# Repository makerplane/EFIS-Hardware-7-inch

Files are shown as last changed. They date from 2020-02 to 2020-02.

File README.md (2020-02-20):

# EFIS-Hardware-7-inch
Hardware design files for 7" EFIS display

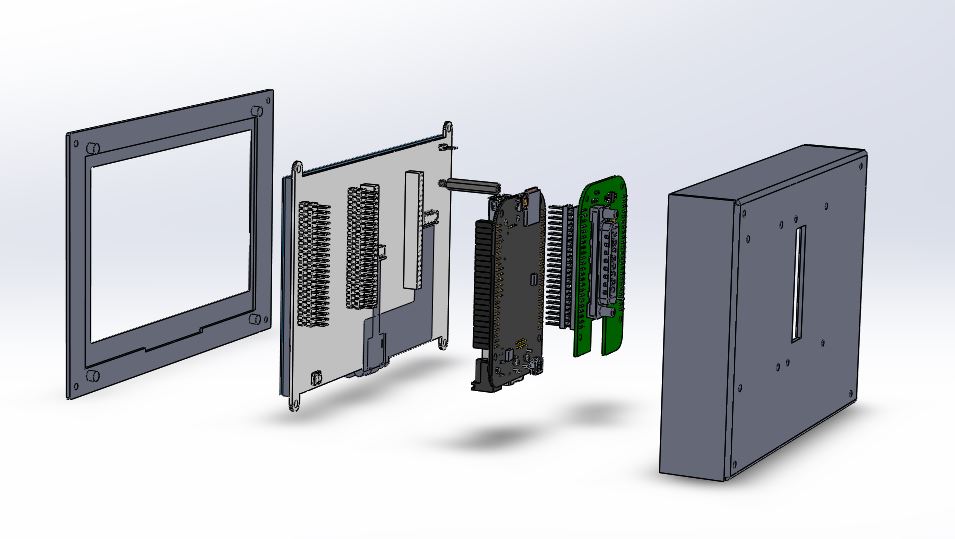
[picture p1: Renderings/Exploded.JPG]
Exploded View


Other required hardware:

[Beaglebone Black Rev C](https://www.digikey.com/product-detail/en/ghi-electronics-llc/BBB01-SC-505/BBB01-SC-505-ND/6210999)

[Newhaven 7" Display Cape](https://www.digikey.com/product-detail/en/newhaven-display-intl/NHD-7.0CTP-CAPE-N/NHD-7.0CTP-CAPE-N-ND/6622772)

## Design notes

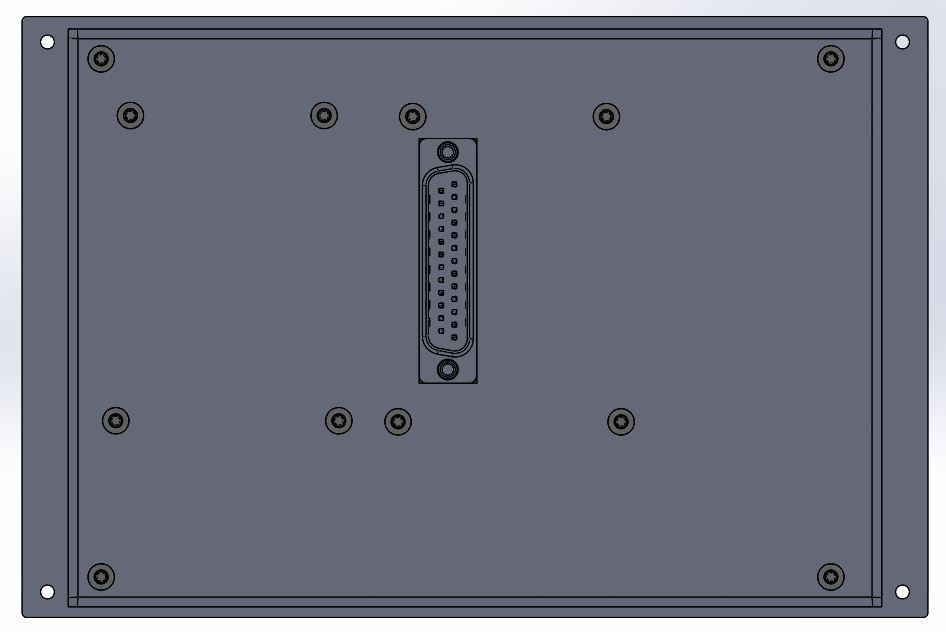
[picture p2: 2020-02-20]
Renderings/Back.JPG

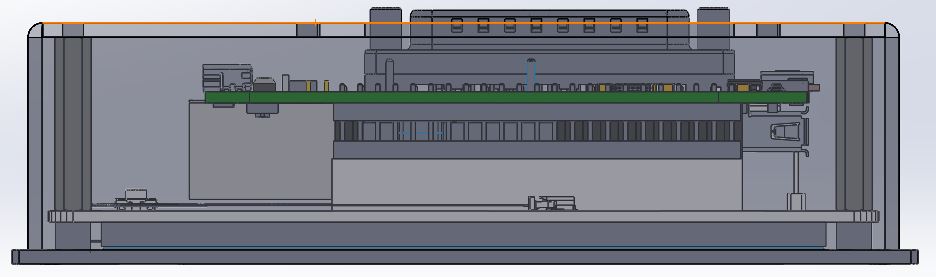
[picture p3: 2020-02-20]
Renderings/Cross Section Side.JPG

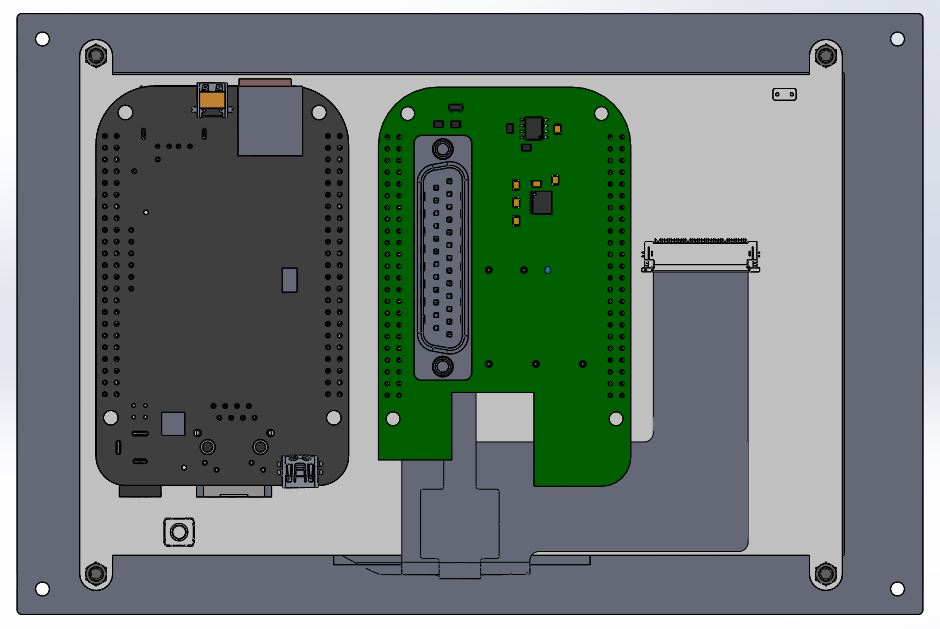
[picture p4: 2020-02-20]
Renderings/Back Removed.JPG

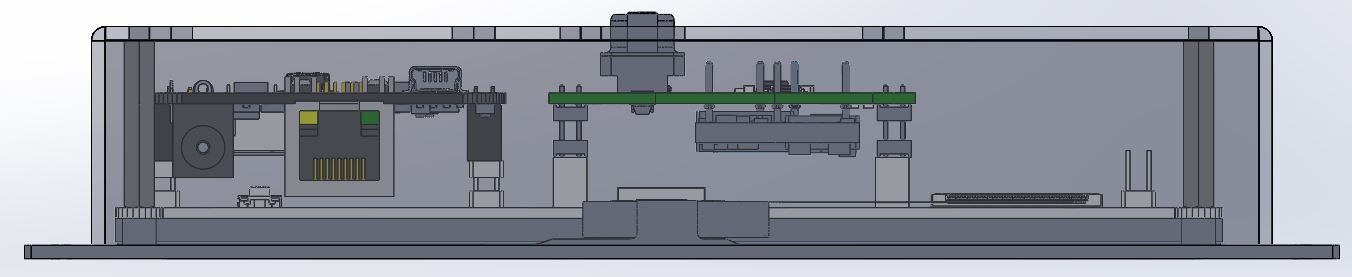
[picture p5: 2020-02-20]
Renderings/Cross Section Bottom.JPG

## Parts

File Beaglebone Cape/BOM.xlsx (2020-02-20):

Digikey Part | Part Number | Description | Designator | Quantity
 | DW-23-09-T-D-315 | CONN HDR 46POS 0.1 STACK T/H TIN |  | 2
609-1503-ND | D25P24A4GV00LF | DSUB25 Male |  | 1
MAX3232ECUE+TCT-ND | MAX3232ECUE+ | RS-232 Driver |  | 1
IRLML0030TRPBFCT-ND | IRLML0030TRPbF | Transistor | Q1 | 1
811-3682-ND | UEI15-050-Q12N-C | DC DC Converter 5V 15W |  | 1
296-11654-1-ND | SN65HVD230DR | IC TXRX CAN 1MBPS 3.3V 8SOIC |  | 1
A129738CT-ND | CRGCQ0805F120R | CRGCQ 0805 120R 1% |  | 1
1772-1896-ND‎ | ‎M2120-3005-AL‎ | HEX STANDOFF M3X0.5 ALUM 25MM |  | 4
‎1772-1109-ND‎ | ‎M1253-3005-AL‎ | HEX STANDOFF M3X0.5 ALUMINUM 6MM |  | 8

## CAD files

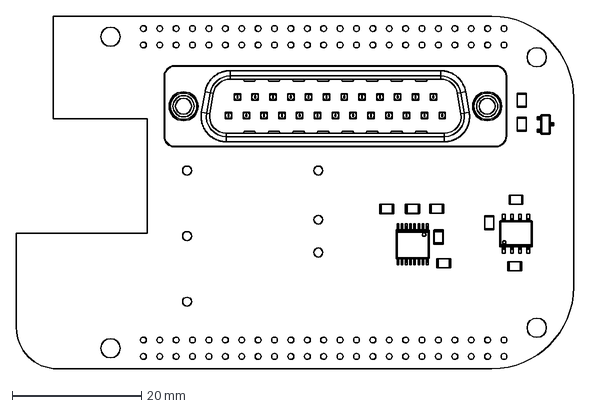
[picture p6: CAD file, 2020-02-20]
Beaglebone Cape/BeagleBoneCape Front.DXF
86.4 x 54.6 mm

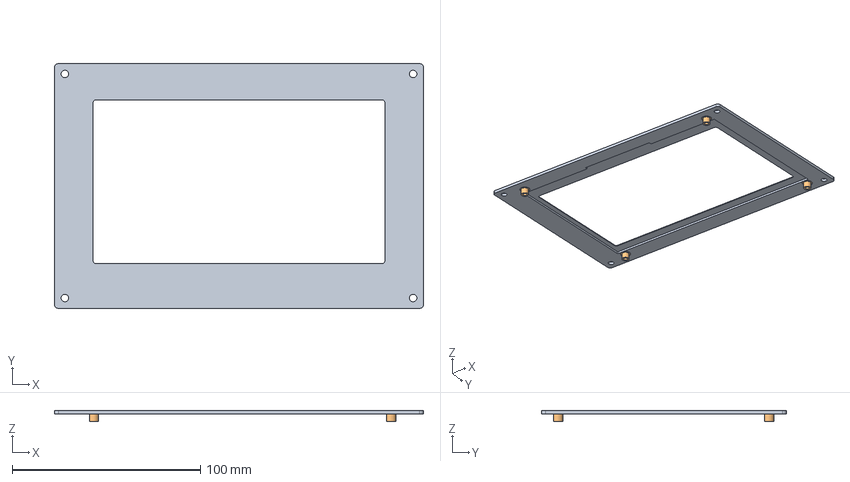
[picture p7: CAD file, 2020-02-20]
Enclosure/Front Panel.stp
196.0 x 130.0 x 6.00 mm

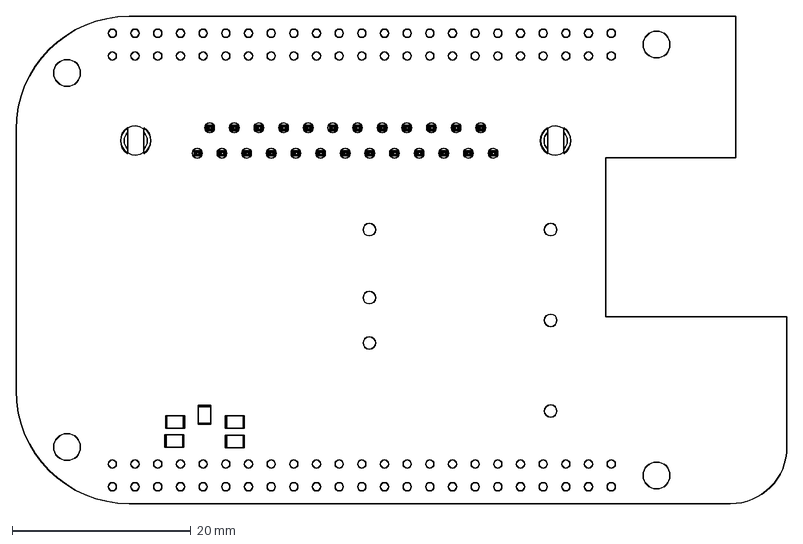
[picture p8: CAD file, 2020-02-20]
Beaglebone Cape/BeagleBoneCape Back.DXF
86.4 x 54.6 mm

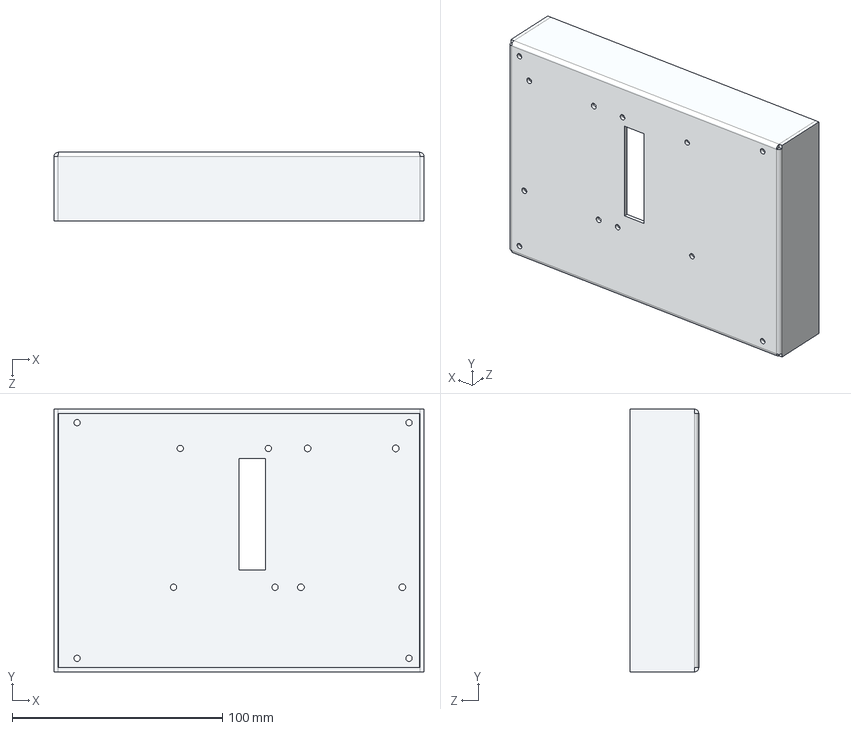
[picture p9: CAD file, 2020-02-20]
Enclosure/Back Case.STEP
176.0 x 125.0 x 32.6 mm

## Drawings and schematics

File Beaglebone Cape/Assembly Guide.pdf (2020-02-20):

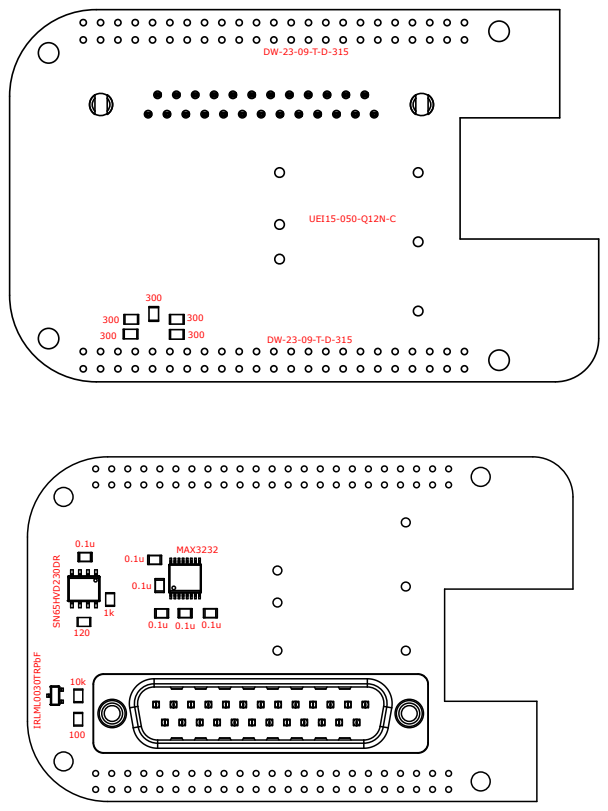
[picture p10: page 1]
MAX3232; SN65HVD230DR; IRLML0030TRPbF; UEI15-050-Q12N-C

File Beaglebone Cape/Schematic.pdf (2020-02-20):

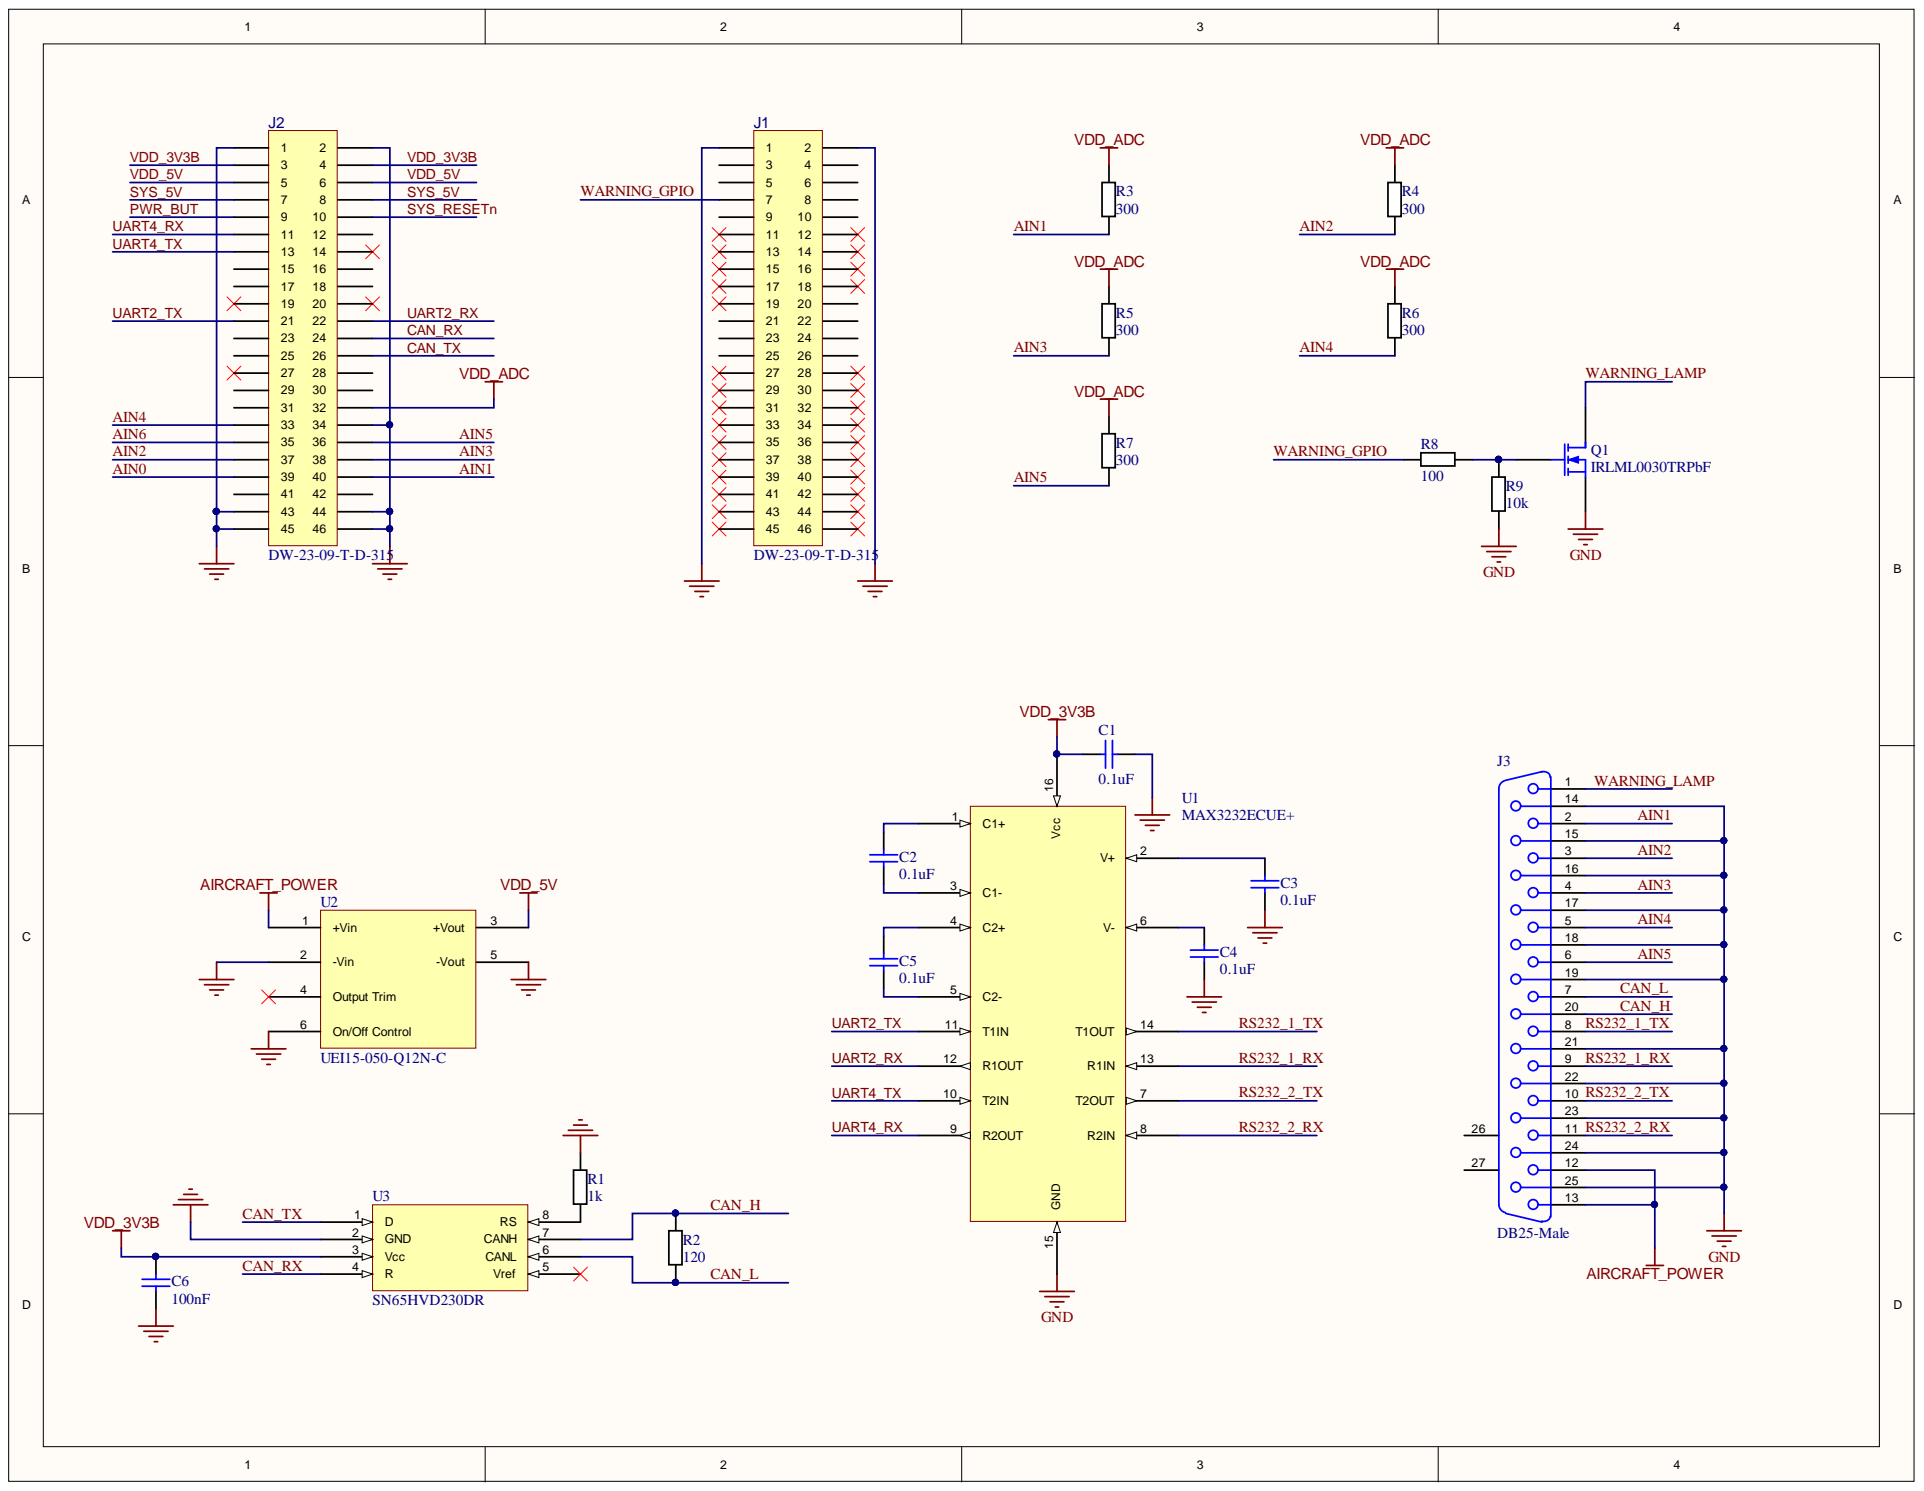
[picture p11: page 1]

VDD_5V
SYS_5V

CAN_RX
CAN_TX

VDD_ADC

AIN5
AIN3

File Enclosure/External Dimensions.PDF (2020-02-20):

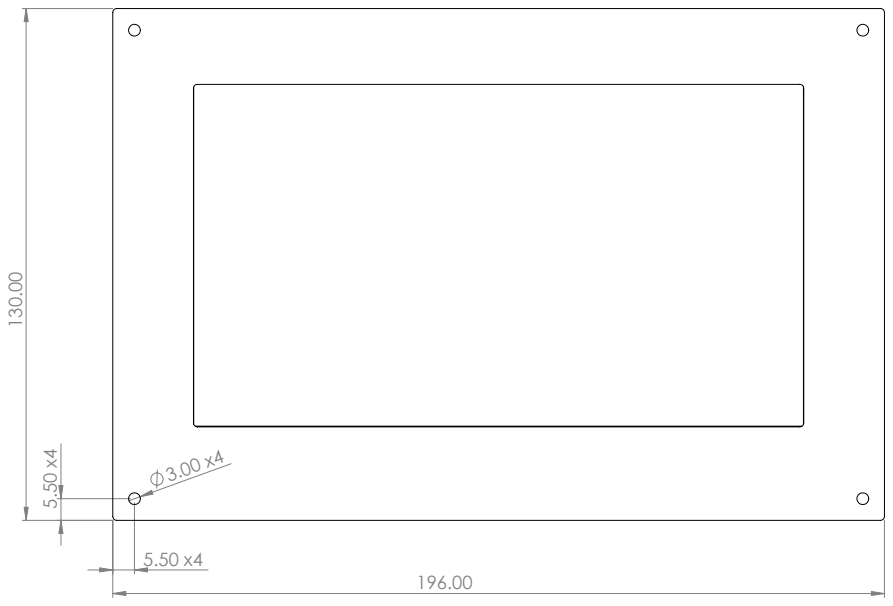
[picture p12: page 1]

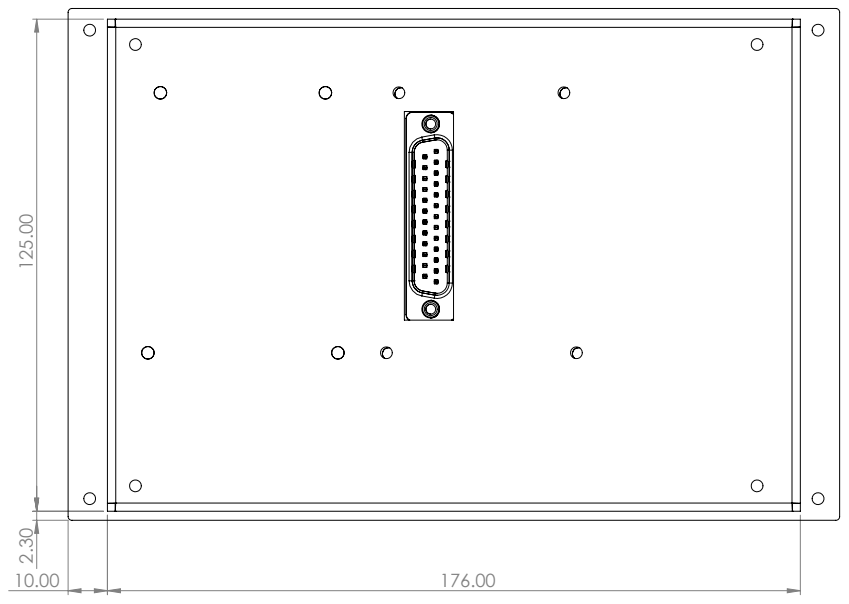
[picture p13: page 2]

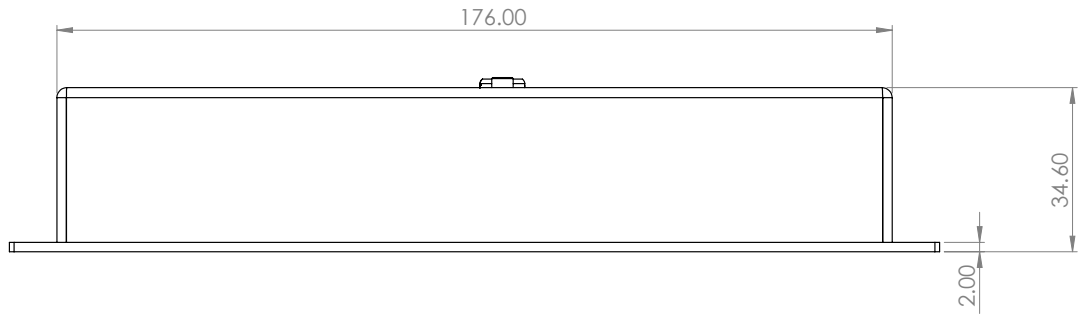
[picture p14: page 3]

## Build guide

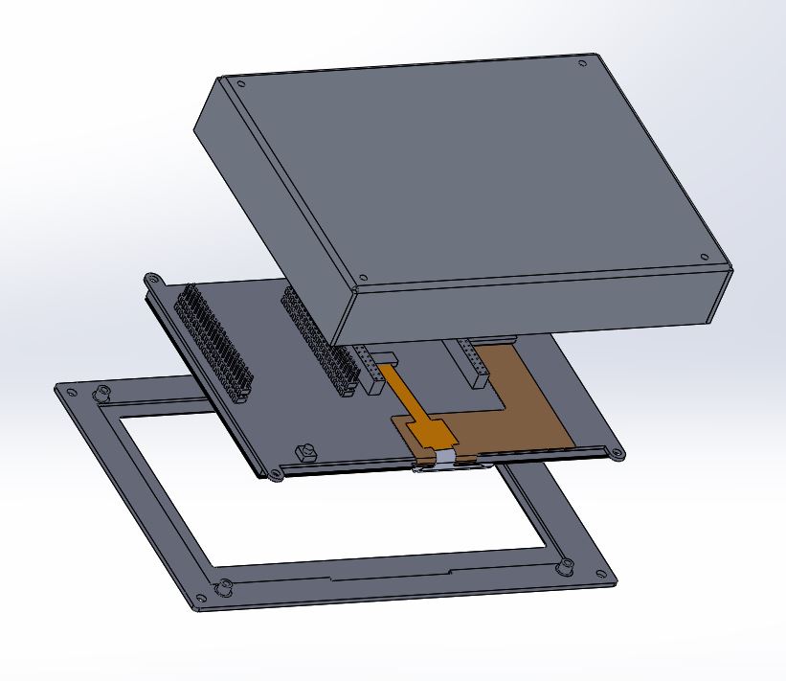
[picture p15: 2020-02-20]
Renderings/Beaglebone Assembly.JPG

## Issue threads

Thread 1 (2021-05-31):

BRD files?

wmax351, 2021-05-31:
Are the board files for the beaglebone cape available?

birkelbach, 2021-06-02:
I'm not sure I'll ask the guy that designed that board.  He doesn't like to release board files so probably not.

j-omega, 2021-06-02:
They need some cleanup, but I will try to get them posted this week.

wmax351, 2021-06-02:
Awesome, thanks!

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

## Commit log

2020-02-20 Added assembly renderings
2020-02-20 Uploaded Beaglebone cape BOM
    [BOM.xlsx]
2020-02-20 Added schematics
    [BeagleBoneCape Back.DXF, BeagleBoneCape Front.DXF]
2020-02-20 Added mechanical files
    [Back Case.STEP]
2020-02-20 Added more mechanical files
    [Front Panel.stp]
